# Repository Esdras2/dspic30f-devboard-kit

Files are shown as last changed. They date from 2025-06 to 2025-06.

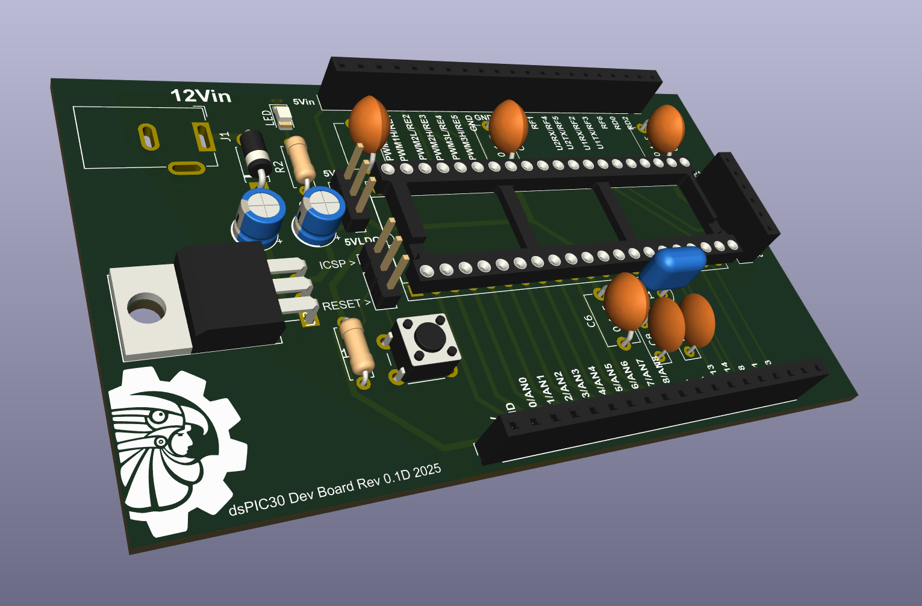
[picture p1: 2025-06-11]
docs/visor_3d_rev_d.png

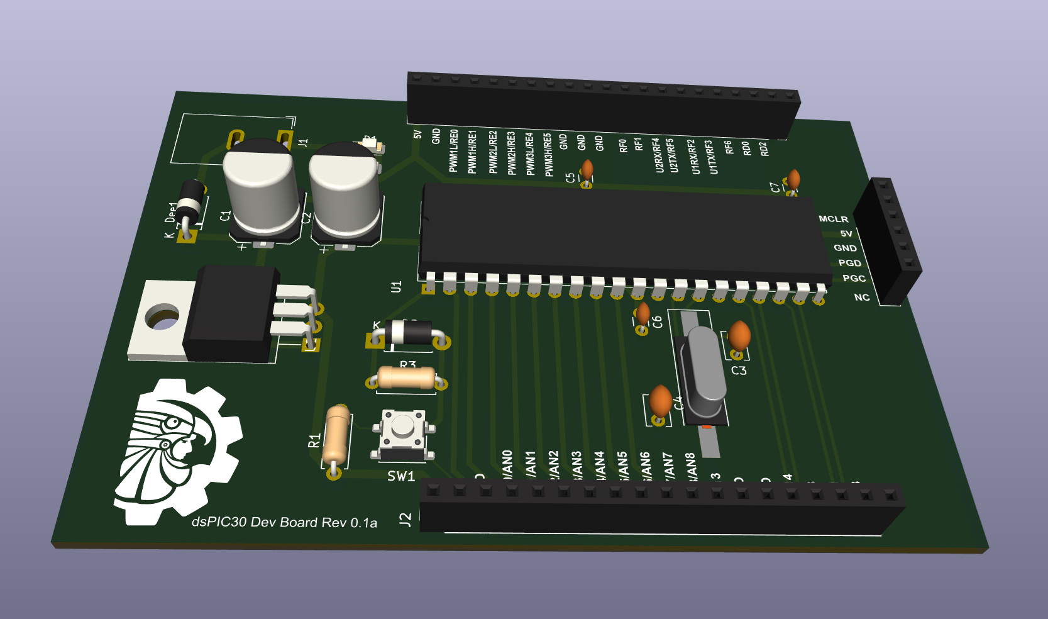
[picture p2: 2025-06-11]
docs/visor_3d_rev_a.png

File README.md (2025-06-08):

# dsPIC30F4011 DIP-40 Development Board  
*A through-hole, single-supply platform for mixed-signal DSP labs*

  
  


> Compact, **breadboard-friendly** board built around Microchip’s  
> **dsPIC30F4011 (DIP-40)**. Ideal for university courses and hobbyists who need a low-cost, fully-THT solution for real-time DSP, motor-control, or instrumentation projects.

---

## 📑 Table of Contents
1. [Key Features (Rev D)](#key-features-rev-d)  
2. [Hardware Revisions](#hardware-revisions)  
3. [Folder Structure](#folder-structure)  
4. [Quick Start](#quick-start)  
5. [Bill of Materials](#bill-of-materials)  
6. [Contributing](#contributing)  
7. [License](#license)  
8. [Resumen rápido en español](#resumen-rápido-en-español)

---

## Key Features (Rev D)

| Block | Details |
|---|---|
| **Power** | 12 V DC barrel jack → **on-board 5 V LDO** (LM7805) |
| **CPU** | **dsPIC30F4011**, 30 MIPS, **socket pads widened** for easy solder/rework |
| **Clock** |  precise UART/DSP timing |
| **Reset** | Single **RC + Schmitt trigger** → faster boot, ~50 % parts count cut |
| **ICSP** | Standard 6-pin header (Pickit 3/4 compatible) |
| **Service** | **Bridge jumpers** isolate power, ICSP, and analog rails → safe bring-up / troubleshooting |
| **Silkscreen** | Pin name on **every** MCU pad + labelled test points |
| **Form Factor**  | 52 mm × 45 mm PCB (≈18 % smaller than Rev B) — fits 70 mm breadboards |

*Full schematic, 3-D renders, PDFs, and Gerbers live in `/hardware/Rev_D/`.*

---

## Hardware Revisions

| Rev | Focus | Major Changes |
|-----|---|---|
| **B** | First production | Base THT design, 12 V→5 V regulation, full silkscreen |
| **C** | Bug-fix & size reduction  | Fixed reversed barrel polarity, wired V<sub>REF±</sub>; **PCB shrunk** 63 × 52 mm → 52 × 45 mm |
| **D** | Serviceability & accuracy | Simplified reset, **larger socket pads**, bridge jumpers, **crystal oscillator added** |

*Older spins remain for reference; **Rev D** is the recommended build.*

---

## Folder Structure
```text
.
├── hardware/         # KiCad 8 projects
│   ├── Rev_B/
│   ├── Rev_C/
│   └── Rev_D/
├── firmware/         # MPLAB X XC16 demo code (blinky, UART loop-back, FIR demo)
├── docs/             # Schematics (PDF), BOMs (CSV/XLSX), 3-D STEP
└── README.md
```

---

## Quick Start

### 1 · Clone & Open Hardware

```bash
git clone https://github.com/<your-org>/dsPIC30F4011-THT.git
cd dsPIC30F4011-THT/hardware/Rev_D
kicad Rev_D.kicad_pro    # KiCad ≥ 8.0
```

### 2 · Generate Gerbers

KiCad → **File ▸ Plot** → select *Gerber* + *Drill*; zip and send to JLCPCB / PCBWay / OSH Park.

### 3 · Assemble

All parts are **through-hole**; ideal for hand-soldering or wave machines.
*Tip :* keep bridge jumpers **open** on first power-up.

### 4 · Flash the Demo

TBD

---

## Bill of Materials (excerpt)

| Qty | Designator | Part & Link | Note |
| --- | --- | --- | --- |
| 1 | U1 | dsPIC30F4011-I/P | 40-pin DIP, 30 MIPS  |
| 1 | X1 | Crystal 7 .3728 MHz | HC-49S |
| 2 | C7, C8 | 22 pF NP0 | Crystal load caps |
| 1 | IC1 | LM7805 | TO-220, 1 A |
| 8 | C1…C8 | 100 nF MLCC | Decoupling (per VDD) |

*See* `docs/BOM_Rev_D.xlsx` *for the full list with supplier SKUs.*

---

## Contributing
TBD

Bug reports and board mods are welcome!

---

## License

All hardware, firmware, and documents are released under the **MIT License**.
See the [LICENSE](LICENSE) file for details.

---

## Resumen rápido (español)

* Placa educativa **THT** con **dsPIC30F4011**.
* Rev D añade cristal, jumpers de aislamiento y pads más amplios.
* Archivos KiCad 8 en `/hardware/Rev_D/`; BOM completa en `docs/`.
* Programación vía ICSP con Pickit 3/4.

¡Felices prototipos! 🎉

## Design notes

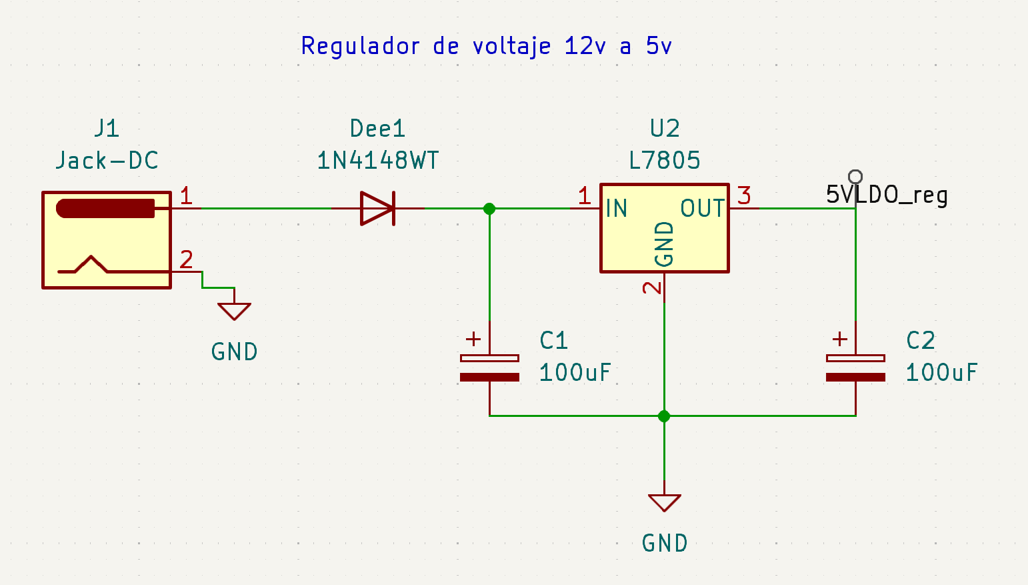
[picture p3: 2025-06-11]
docs/001_circuito_regulador_lineal_5v.png

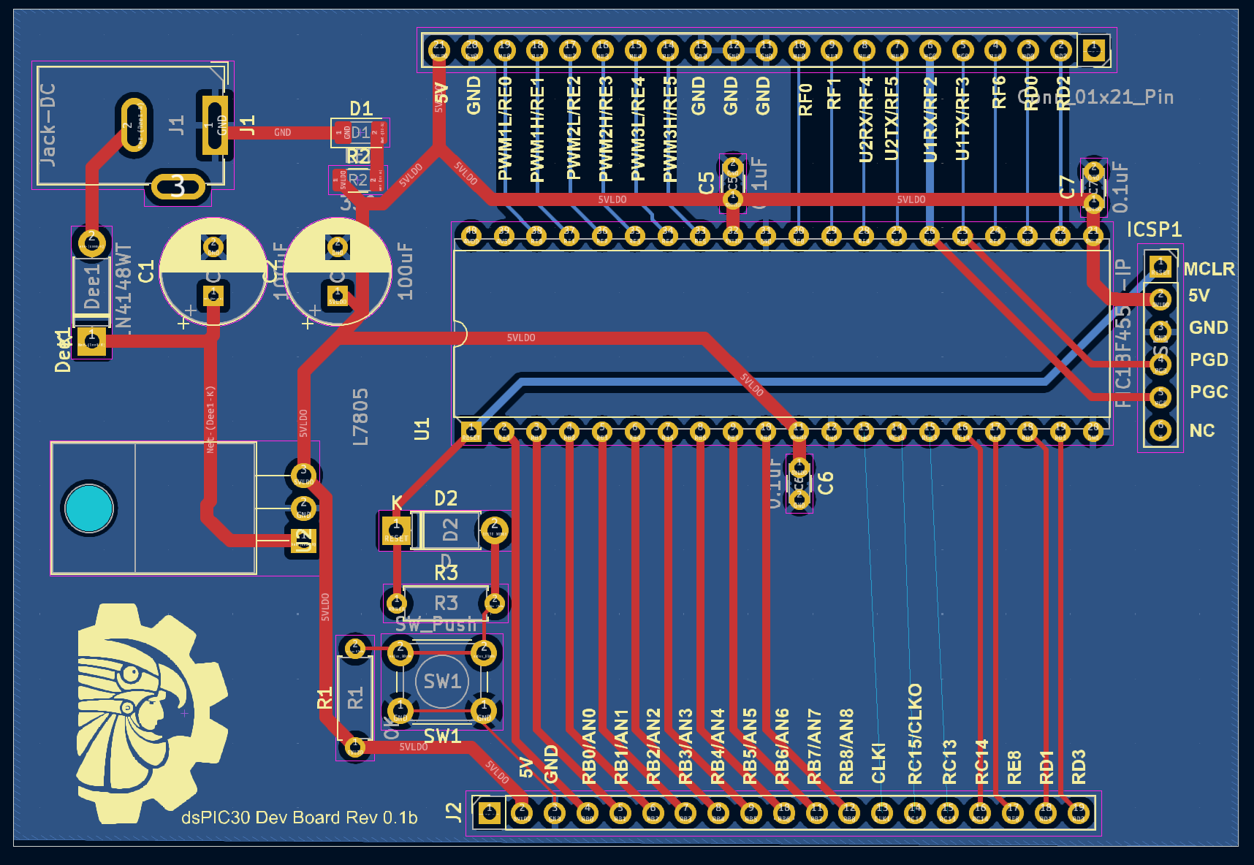
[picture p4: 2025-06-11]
docs/PCB_board_rev_b.png

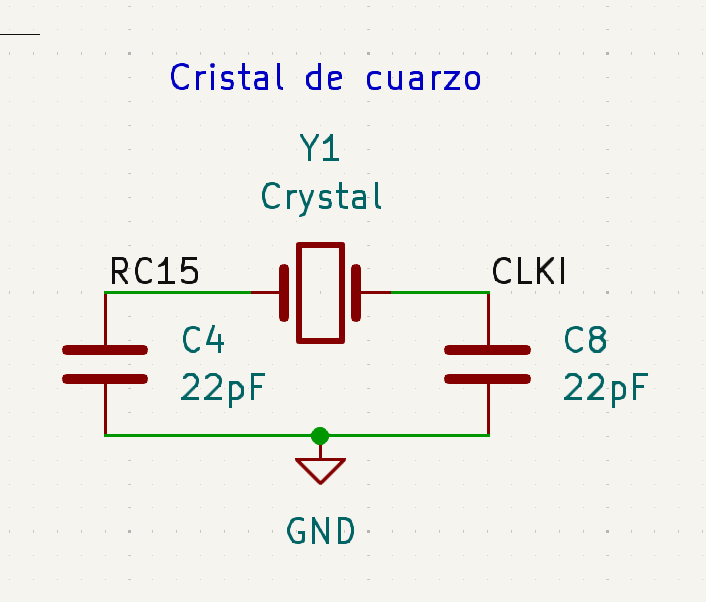
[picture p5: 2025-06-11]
docs/003_cristal_cuarzo.png

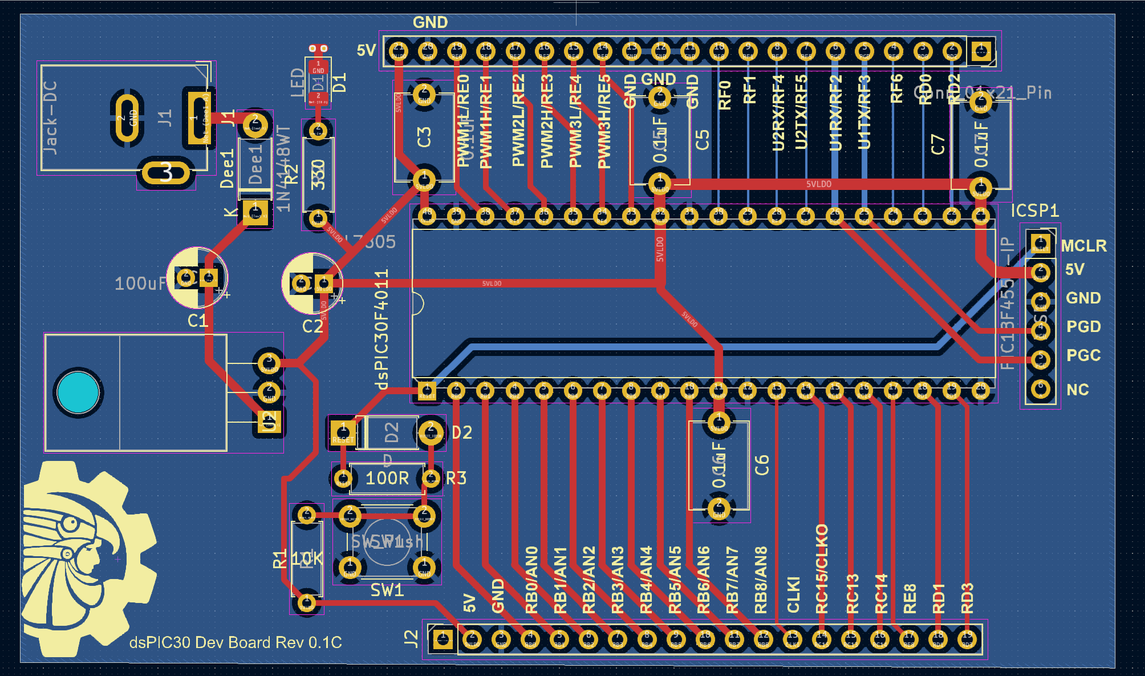
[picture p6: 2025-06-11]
docs/PCB_board_rev_c.png

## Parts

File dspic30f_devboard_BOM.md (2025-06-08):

## 📋 Bill of Materials (BOM)

| Designator  | Qty | Value / Spec | Footprint | Manufacturer | MPN | Descripción breve |
| --- | --: | --- | --- | --- | --- | --- |
| **U1** | 1 | dsPIC30F4011 | DIP-40 | Microchip | dsPIC30F4011-I/P | DSC 16-bit @ 30 MIPS |
| **U2** | 1 | 5 V @ 1 A LDO | TO-220-3 (horizontal, RM 2.54 mm) | ST | L4941BV | Regulador lineal 5 V |
| **D1** | 1 | LED rojo | SMD 1206 | Lite-On | LTST-C170KRKT | Indicador de estado |
| **Y1** | 1 | 7.3728 MHz | Resonator 2-pin (W 8 mm × H 3.5 mm) | CTS | 402C37.3728 | Cristal ±20 ppm |
| **C1, C2**  | 2 | 22 pF | Radial Ø 5 mm, P 2 mm | Murata | CC45SL3FD220JYNN | Carga para cristal |
| **C3 – C8** | 6 | 0.1 µF | Radial Ø 7.5 mm, P 5 mm | KEMET | C330C104K5R5TA | Desacople V<sub>DD</sub> |
| **C9, C10** | 2 | 100 µF 25 V | Electrol. Ø 5 mm, P 2 mm | Panasonic | EEU-FC1E101 | Filtro de entrada |
| **R1** | 1 | 10 kΩ ±5 % | DIN0207 L 6.3 mm, P 7.62 mm | Yageo | CFM14JT10K0 | Pull-up / reset |
| **R2** | 1 | 330 Ω ±5 % | DIN0207 L 6.3 mm, P 7.62 mm | Yageo | CFM14JT330R | Limitador LED |
| **J1** | 1 | Header 1 × 6 (2.54 mm) | PinHeader vertical | Amphenol | 61300611121 | ICSP |
| **J2** | 1 | Barrel jack 5.5 × 2.1 mm | BarrelJack horizontal | CUI | PJ-102A | Entrada DC 12 V |
| **J3 – J5** | 3 | Header 1 × 2 (2.54 mm) | PinHeader vertical | Amphenol | 61300211121 | Puentes de test |

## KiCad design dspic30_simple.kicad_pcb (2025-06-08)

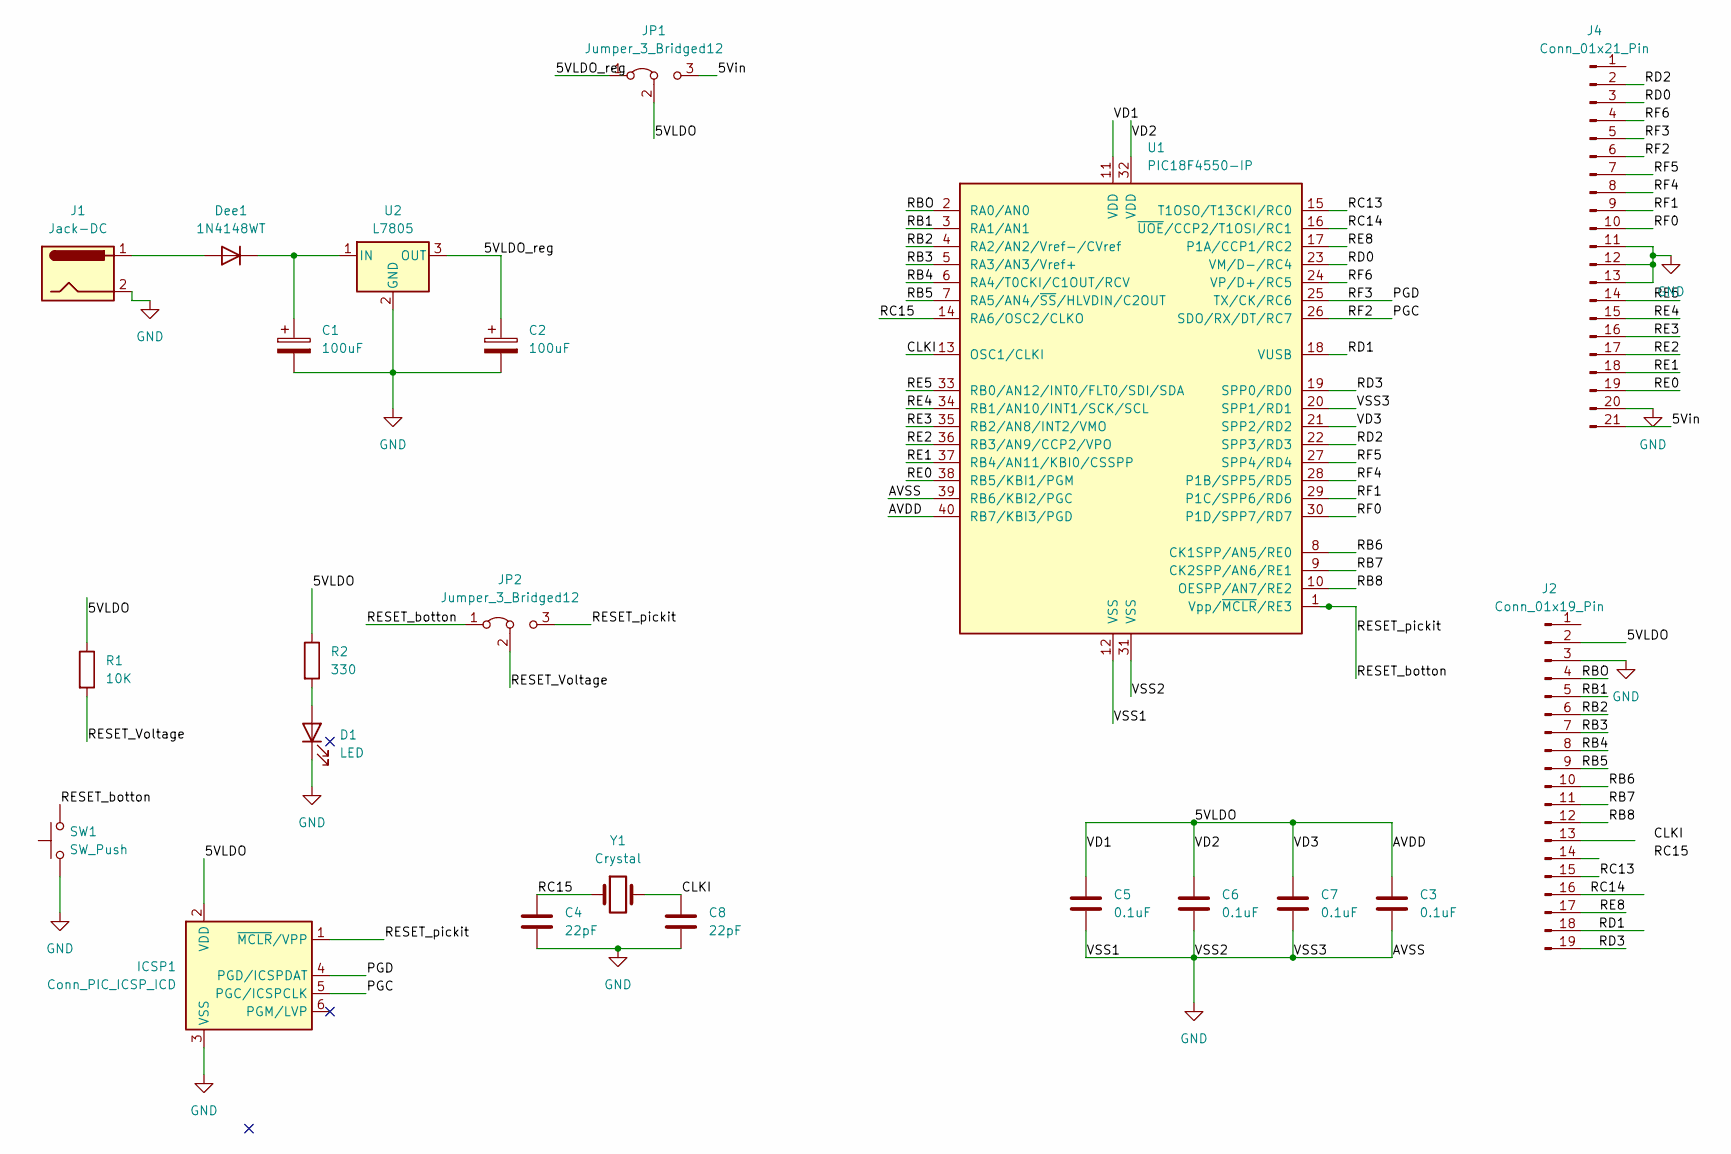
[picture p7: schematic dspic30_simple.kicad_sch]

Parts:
C1, C2: 100uF; CP_Radial_D5.0mm_P2.00mm
C3, C5, C6, C7: 0.1uF; C_Disc_D7.5mm_W5.0mm_P7.50mm
C4, C8: 22pF; C_Disc_D7.0mm_W2.5mm_P5.00mm
D1: LED; LED_1206_3216Metric
Dee1: 1N4148WT; D_DO-41_SOD81_P7.62mm_Horizontal
ICSP1: Conn_PIC_ICSP_ICD; PinSocket_1x06_P2.54mm_Vertical
J1: Jack-DC; BarrelJack_GCT_DCJ200-10-A_Horizontal
J2: Conn_01x19_Pin; PinSocket_1x19_P2.54mm_Vertical
J4: Conn_01x21_Pin; PinSocket_1x21_P2.54mm_Vertical
JP1, JP2: Jumper_3_Bridged12; PinHeader_1x03_P2.54mm_Vertical
R1: 10K; R_Axial_DIN0207_L6.3mm_D2.5mm_P7.62mm_Horizontal
R2: 330; R_Axial_DIN0207_L6.3mm_D2.5mm_P7.62mm_Horizontal
SW1: SW_Push; SW_PUSH_6mm
U1: PIC18F4550-IP; DIP-40_W15.24mm_Socket
U2: L7805; TO-220-3_Horizontal_TabDown
Y1: Crystal; Resonator-2Pin_W8.0mm_H3.5mm

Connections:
/5VLDO: C3.1, C5.1, C6.1, C7.1, ICSP1.2 (VDD), J2.2, JP1.2 (C), R1.1, R2.1, U1.11 (VDD), U1.21 (SPP2/RD2), U1.32 (VDD), U1.40 (RB7/KBI3/PGD)
/5VLDO_reg: C2.1, JP1.1 (A), U2.3 (OUT)
/5Vin: J4.21, JP1.3 (B)
/CLKI: C8.1, U1.13 (OSC1/CLKI), Y1.2
/PGC: ICSP1.5 (PGC/ICSPCLK), J4.6, U1.26 (SDO/RX/DT/RC7)
/PGD: ICSP1.4 (PGD/ICSPDAT), J4.5, U1.25 (TX/CK/RC6)
/RB1: J2.5, U1.3 (RA1/AN1)
/RB2: J2.6, U1.4 (RA2/AN2/Vref-/CVref)
/RB3: J2.7, U1.5 (RA3/AN3/Vref+)
/RB4: J2.8, U1.6 (RA4/T0CKI/C1OUT/RCV)
/RB5: J2.9, U1.7 (RA5/AN4/~SS/HLVDIN/C2OUT)
/RB6: J2.10, U1.8 (CK1SPP/AN5/RE0)
/RB7: J2.11, U1.9 (CK2SPP/AN6/RE1)
/RB8: J2.12, U1.10 (OESPP/AN7/RE2)
/RBO: J2.4, U1.2 (RA0/AN0)
/RC13: J2.15, U1.15 (T1OSO/T13CKI/RC0)
/RC14: J2.16, U1.16 (~UOE/CCP2/T1OSI/RC1)
/RC15: C4.1, U1.14 (RA6/OSC2/CLKO), Y1.1
/RD0: J4.3, U1.23 (VM/D-/RC4)
/RD1: J2.18, U1.18 (VUSB)
/RD2: J4.2, U1.22 (SPP3/RD3)
/RD3: J2.19, U1.19 (SPP0/RD0)
/RE0: J4.19, U1.38 (RB5/KBI1/PGM)
/RE1: J4.18, U1.37 (RB4/AN11/KBI0/CSSPP)
/RE2: J4.17, U1.36 (RB3/AN9/CCP2/VPO)
/RE3: J4.16, U1.35 (RB2/AN8/INT2/VMO)
/RE4: J4.15, U1.34 (RB1/AN10/INT1/SCK/SCL)
/RE5: J4.14, U1.33 (RB0/AN12/INT0/FLT0/SDI/SDA)
/RE8: J2.17, U1.17 (P1A/CCP1/RC2)
/RESET_Voltage: JP2.2 (C), R1.2
/RESET_botton: ICSP1.1 (~MCLR/VPP), JP2.1 (A), JP2.3 (B), SW1.2, U1.1 (Vpp/~MCLR/RE3)
/RF0: J4.10, U1.30 (P1D/SPP7/RD7)
/RF1: J4.9, U1.29 (P1C/SPP6/RD6)
/RF4: J4.8, U1.28 (P1B/SPP5/RD5)
/RF5: J4.7, U1.27 (SPP4/RD4)
/RF6: J4.4, U1.24 (VP/D+/RC5)
GND: C1.2, C2.2, C3.2, C4.2, C5.2, C6.2, C7.2, C8.2, D1.1 (K), ICSP1.3 (VSS), J1.2, J2.3, J4.11, J4.12, J4.13, J4.20, SW1.1, U1.12 (VSS), U1.20 (SPP1/RD1), U1.31 (VSS), U1.39 (RB6/KBI2/PGC), U2.2 (GND)
unnamed: D1.2 (A), R2.2
unnamed: Dee1.2 (A), J1.1
unnamed: C1.1, Dee1.1 (K), U2.1 (IN)

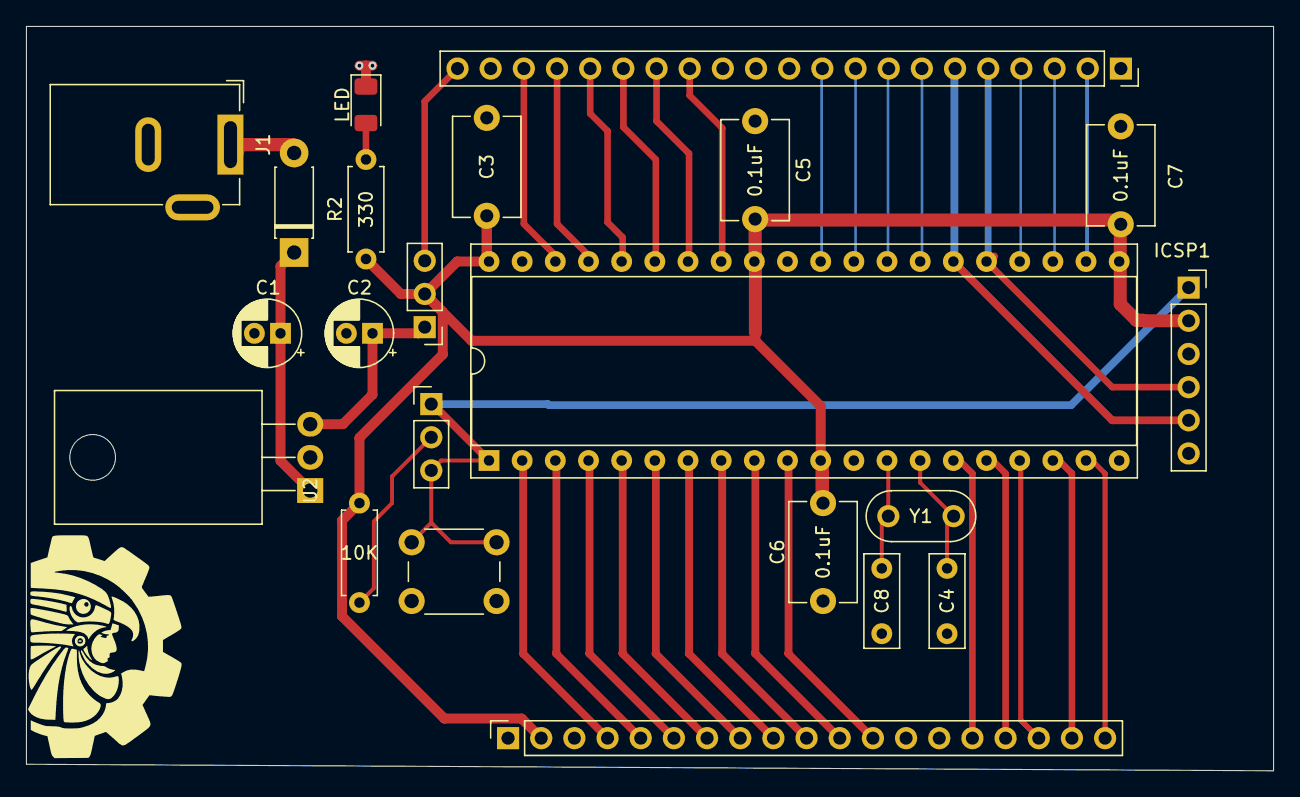
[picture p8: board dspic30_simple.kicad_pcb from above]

Board: 2 copper layers, 95.5 x 57.0 mm, 22 parts (0 on the bottom side), 40 nets.

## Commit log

2025-03-20 init smd ended rev 0.1a
    [dspic30_simple.kicad_pcb, dspic30_simple.kicad_sch]
2025-03-20 initial rev 0.1b
    [dspic30_simple.kicad_pcb]
2025-03-20 changes smd component for tht components
    [dspic30_simple-B_Cu.gbr, dspic30_simple-B_Mask.gbr, dspic30_simple-Edge_Cuts.gbr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]
2025-03-20 fix GDN not connnected
    [dspic30_simple-B_Cu.gbr, dspic30_simple-B_Mask.gbr, dspic30_simple-Edge_Cuts.gbr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]
2025-03-20 GND DRC warnings
    [dspic30_simple-B_Cu.gbr, dspic30_simple-B_Mask.gbr, dspic30_simple-Edge_Cuts.gbr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]
2025-05-02 fix conflicts
    [dspic30_simple.kicad_pcb, dspic30_simple.kicad_sch]
2025-06-08 revision rev D
    [dspic30_simple.kicad_pcb, dspic30_simple.kicad_sch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]
2025-06-08 mejora de archivo gitignore
2025-06-08 se añade lista BOM de materiales
2025-06-08 remove no longer needed folder, files
    [dspic30_simple-B_Cu.gbr, dspic30_simple-B_Mask.gbr, dspic30_simple-Edge_Cuts.gbr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]

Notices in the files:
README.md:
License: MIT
